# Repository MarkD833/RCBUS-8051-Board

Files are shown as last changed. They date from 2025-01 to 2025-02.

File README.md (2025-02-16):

# RCBUS-8051-Board

I've recently re-discovered some of the microprocessors and microcontrollers from my youth via the [RC2014 website](https://rc2014.co.uk/) and the numerous boards available on [Steve Cousins website](https://smallcomputercentral.com/).

The ecosystem is dominated by the Z80 processor and the various Z80 peripheral chips from that era along with the CP/M operating system which the hardware can run.

My introduction to computing started with an 8051 microcontroller and I've got an itch to have a go at putting together an 8051 design that will be compatible with the more open RCBus system. My background isn't hardware so apologies to the hardware designers for the horrors that I'm about to unleash!

# My 8051 RCBus offering
## The 8051 microcontroller
Whilst wanting to retain the retro experience, I wanted to skip the use of a UV eraser - as I don't have one! I initially settled on an ATMEL AT89C51RB2 device as it could be programmed by invoking an interal bootloader and using the free ATMEL FLIP software to program it in-circuit. For the most part it worked - with one HUGE gotcha!

It took me a while to figure it out but after re-reading the datasheet I discovered that there was a fuse bit that prohibited the device from executing code in external memory. The problem was that FLIP can't reprogram this bit to enable external program execution and a parallel programmer was required. My XGecu T48 programmer doesn't support the AT89C51RB2 and I wasn't about to purchase a new PROM programmer just to program this chip.

After searching for a suitable alternative device, I settled on the ATMEL AT89S8253 which is MCS51 compatible.

## External memory
I needed the ability to write to program memory to load code and I wanted to experiment to see if I could come up with a desgin that would be able to switch between the 8051's [Harvard architecture](https://en.wikipedia.org/wiki/Harvard_architecture) (where program memory and data memory are normally separate) and a [von Neumann architecture](https://en.wikipedia.org/wiki/Von_Neumann_architecture).

In order to have the maximum amount of code space and data space, I would need a 128K SRAM device.

## The RCBus
The RCBus supports both memory space and IO space. As I was going to have the maximum amout of addressable memory on-board, off-board memory space was not going to be supported. IO space is 256 bytes and is mapped into the data memory map.

# The design (so far...)
The design at v1.1 is shown in the image below. The board is hopefully the size of the RCBus "medium" module with a 40 pin edge connector as detailed in the [RCBus specification](https://smallcomputercentral.com/rcbus/) v1.0.

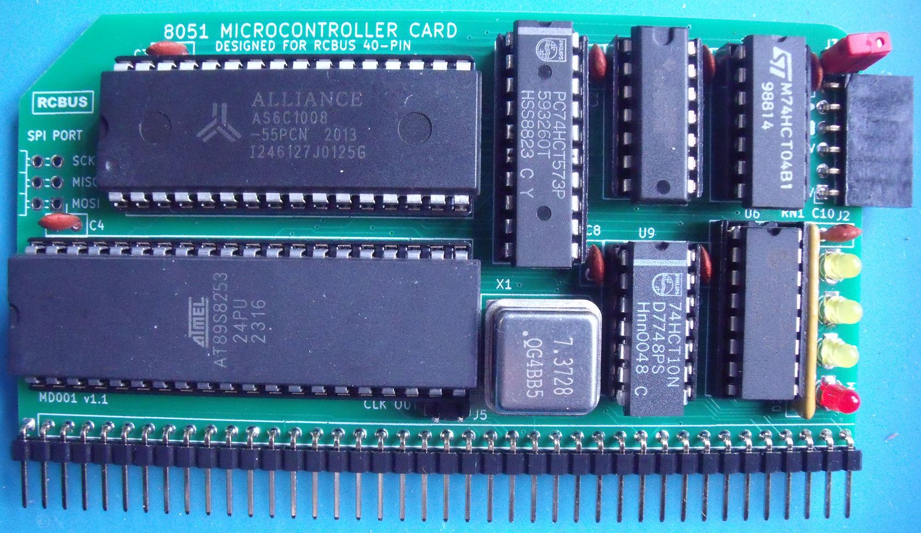
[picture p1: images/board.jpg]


# Memory Map

After a hard reset, the lower 12K of program memory ($0000..$2FFF) resides inside the AT89S8253 as FLASH memory and the bulk of the 64K block of RAM is shared between program space and data space.

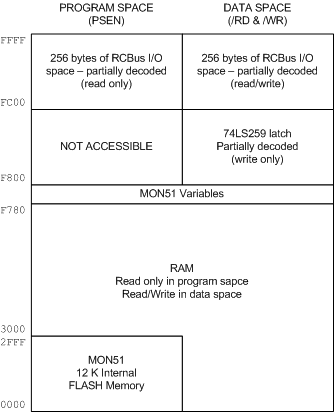
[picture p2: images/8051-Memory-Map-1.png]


# What works
I've ported Dave Dunfields MON51 monitor program over to the 89S8253. Most of the work involved getting the code to assemble using ASEM-51 v1.3 under Windows 10. The modified MON51 (MON51.a51) and original (MON51.ASM) are in the MON51 folder.

Currently:
* MON51 appears to function correctly
* Program space and data space are shared on power up
* Code can be downloaded via MON51 into the shared RAM and executed
* The on-board latch (74LS259) can be written to ($F800..$FBFF)
* RCBus IO space can be accessed ($FC00..$FFFF)
* Program space and data space can be separated (write $01 to $F801)
* Internal reboot works - can execute code in external memory starting at address $0000
 
## RCBus boards
The following boards appear to function correctly with the 8051 micro:
* SC129 Digital I/O Board
* SC704 I2C Bus Master Board (inc SC406 temperature module)
* SC705 Serial ACIA Board
 
# Still to do
* Further checks on the RCBus IO space using a few of Steve Cousins boards

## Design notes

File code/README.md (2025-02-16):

# Test code
This folder holds various pieces of code that test the 8051 board.

The assembler code should assemble under Windows 10 using [ASEM-51 v1.3](https://plit.de/asem-51/download.htm).

The code can be assembled using the simple command:
```
asemw <source-file-name>
```
# 8051 board tests
These bits of code test some functionality on the 8051 board.

## switch1.a51
This is a simple piece of code that tests the ability to separate program space from data space. It outputs a count to the LEDs on an [SC129](https://smallcomputercentral.com/rcbus/sc100-series/sc129-digital-i-o-rc2014/) digital I/O board. When the count reaches 15, the program space and data space are separated and the count should continue.

## switch2.a51
Simialr to switch1.a51 above except that it increments a variable in data space just to prove that the two memories are really separated.  

# RCBus and RC-2014 board test programs
## SC129 Digital I/O Board
The [SC129](https://smallcomputercentral.com/rcbus/sc100-series/sc129-digital-i-o-rc2014/) is a simple digital I/O module available from the [Small Computer Central](https://smallcomputercentral.com/) website.

| File | Description |
| :---- | :---- |
| count.a51 | Counts in binary on the LEDs of an SC129 board. |
| echo.a51 | Reads an SC129 input port and writes to its output port. |

## SC704 I2C Bus Master board
The [SC704](https://smallcomputercentral.com/rcbus/sc700-series/sc704-rcbus-i2c-bus-master/) implements a simple bit banged I2C bus master. As part of the testing, an [SC406](https://smallcomputercentral.com/i2c-bus-modules/sc406-i2c-temperature-sensor-module/) I2C temperature sensor module was used.

| File | Description |
| :---- | :---- |
| i2c_scan.a51 | Simple I2C bus scanner to detect I2C devices and report their addresses. |
| sc406.a51 | Reads the temperature of an SC406 temperature sensor. |

## SC705 Serial ACIA board
The [SC705](https://smallcomputercentral.com/rcbus/sc700-series/sc705-rcbus-serial-acia/) is a single channel UART (MC68B50) with a fixed baud rate (dependant on the external clock applied).

| File | Description |
| :---- | :---- |
| hello.a51 | Outputs "Hello World!" to the port. |
| echo.a51 | Echoes back any characters received. |

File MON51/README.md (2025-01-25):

# MON51 Monitor Program
The 8051 monitor program I'm using to get started is Dave Dunfields MON51. Dave has kindly made available 40+ years of source code via [his website](https://dunfield.themindfactory.com/).

I'm not sure what assembler was used to assemble the original assembly code (MON51.ASM). I therefore modified the code so that it would assemble under Windows 10 using [ASEM-51 v1.3](https://plit.de/asem-51/download.htm).

My modified version of MON51 - called MON51.a51 - for my RCBus 8051 board can be assembled using ASEM51 v1.3. I've also included the original copyright information from Dave Dunfield.

The monitor can be assembled using the simple command:
```
asemw mon51
```

The monitor adds LJMP instructions for the exception vectors to handlers starting at address $3000 and the baud rate is set to 38400 baud.

I've added a new Z command. This will set EA low, separate program memory from data memory (so each has its own memory space of almost 64K : $0000 to $F800) and internally reset the 8051 to execute code from external program memory starting at address $0000.
 
The original source code to MON51 can be found in the MONITOR.ZIP file on Dave's website along with MON51.TXT which is a brief user guide.

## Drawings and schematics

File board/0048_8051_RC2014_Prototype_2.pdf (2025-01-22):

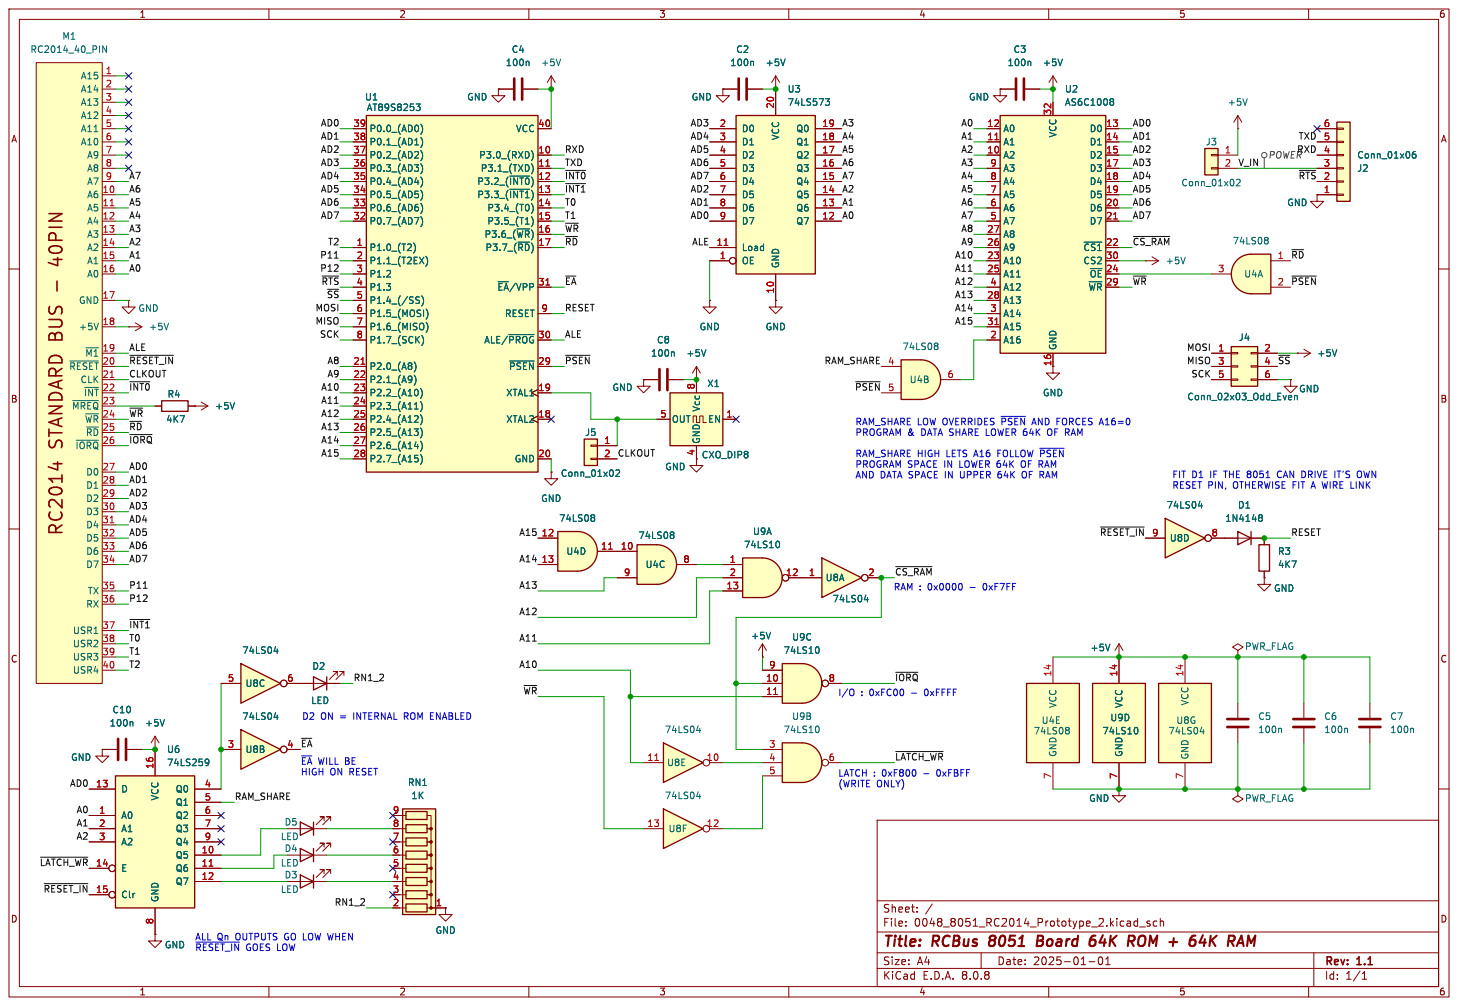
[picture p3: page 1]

A15 1 A6 10 A5 11 A4 12 A3 13 A2 14 A1 15 A0 16 GND 17 +5V 18 ~{M1}19 A14 2 ~{RESET} 20 CLK 21 ~{INT} 22 ~{MREQ} 23 ~{WR} 24 ~{RD} 25 ~{IORQ} 26 D0 27 D1 28 D2 29 A13 3 D3 30 D4 31 D5 32 D6 33 D7 34 TX 35 RX 36 USR1 37 USR2 38 USR3 39
A12 4 USR4 40

RAM_SHARE HIGH LETS A16 FOLLOW ~{PSEN} PROGRAM SPACE IN LOWER 64K OF RAM

AND DATA SPACE IN UPPER 64K OF RAM

RESET PIN, OTHERWISE FIT A WIRE LINK D2 ON = INTERNAL ROM ENABLED

(WRITE ONLY) ALL Qn OUTPUTS GO LOW WHEN

File: 0048_8051_RC2014_Prototype_2.kicad_sch Sheet: /
Id: 1/1 Title: RCBus 8051 Board 64K ROM + 64K RAM

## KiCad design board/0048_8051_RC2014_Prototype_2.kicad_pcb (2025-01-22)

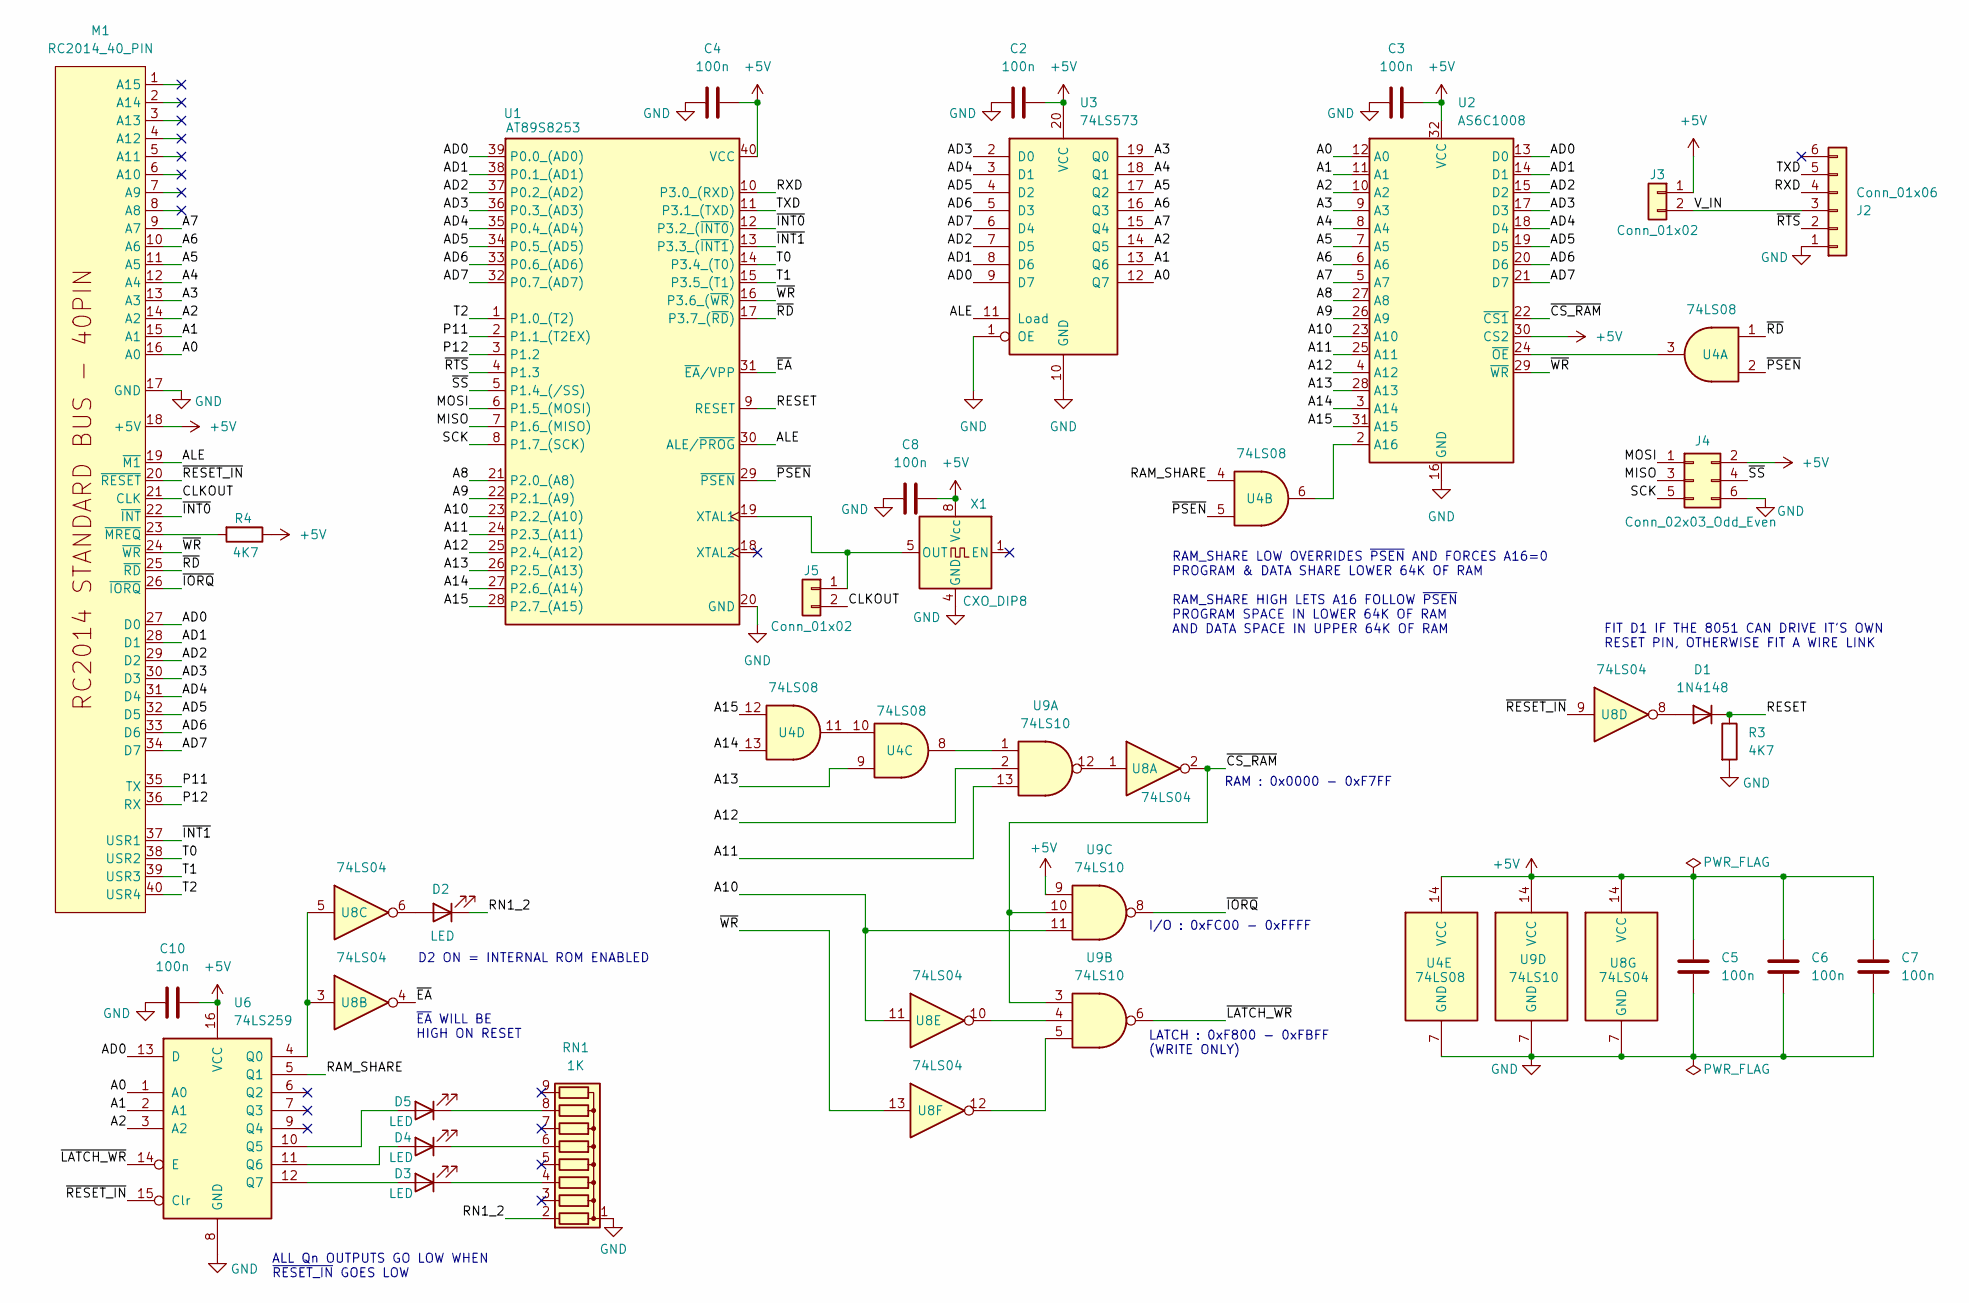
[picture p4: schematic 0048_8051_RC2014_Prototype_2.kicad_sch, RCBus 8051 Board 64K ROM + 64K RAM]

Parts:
C2, C3, C4, C5, C6, C7, C8, C10: 100n; C_Disc_D5.0mm_W2.5mm_P2.50mm
D1: 1N4148; D_DO-35_SOD27_P7.62mm_Horizontal
D2, D3, D4, D5: LED; LED_D3.0mm
J2: Conn_01x06; PinSocket_1x06_P2.54mm_Horizontal
J3, J5: Conn_01x02; PinHeader_1x02_P2.54mm_Vertical
J4: Conn_02x03_Odd_Even; PinHeader_2x03_P2.54mm_Horizontal
M1: RC2014_40_PIN; RCBUS_40P_MEDIUM
R3, R4: 4K7; R_Axial_DIN0207_L6.3mm_D2.5mm_P7.62mm_Horizontal
RN1: 1K; R_Array_SIP9
U1: AT89S8253; DIP-40_W15.24mm_Socket
U2: AS6C1008; DIP-32_W15.24mm_Socket
U3: 74LS573; DIP-20_W7.62mm_Socket
U4: 74LS08; DIP-14_W7.62mm_Socket
U6: 74LS259; DIP-16_W7.62mm_Socket
U8: 74LS04; DIP-14_W7.62mm_Socket
U9: 74LS10; DIP-14_W7.62mm_Socket
X1: CXO_DIP8; Oscillator_DIP-8

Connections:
+5V: C2.2, C3.2, C4.2, C5.1, C6.1, C7.1, C8.2, C10.2, J3.1, J4.2, M1.18 (+5V), R4.1, U1.40 (VCC), U2.30 (CS2), U2.32 (VCC), U3.20 (VCC), U4.14 (VCC), U6.16 (VCC), U8.14 (VCC), U9.9, U9.14 (VCC), X1.8 (Vcc)
/A0: M1.16 (A0), U2.12 (A0), U3.12 (Q7), U6.1 (A0)
/A1: M1.15 (A1), U2.11 (A1), U3.13 (Q6), U6.2 (A1)
/A2: M1.14 (A2), U2.10 (A2), U3.14 (Q5), U6.3 (A2)
/A3: M1.13 (A3), U2.9 (A3), U3.19 (Q0)
/A4: M1.12 (A4), U2.8 (A4), U3.18 (Q1)
/A5: M1.11 (A5), U2.7 (A5), U3.17 (Q2)
/A6: M1.10 (A6), U2.6 (A6), U3.16 (Q3)
/A7: M1.9 (A7), U2.5 (A7), U3.15 (Q4)
/A8: U1.21 (P2.0_(A8)), U2.27 (A8)
/A9: U1.22 (P2.1_(A9)), U2.26 (A9)
/A10: U1.23 (P2.2_(A10)), U2.23 (A10), U8.11, U9.11
/A11: U1.24 (P2.3_(A11)), U2.25 (A11), U9.13
/A12: U1.25 (P2.4_(A12)), U2.4 (A12), U9.2
/A13: U1.26 (P2.5_(A13)), U2.28 (A13), U4.9
/A14: U1.27 (P2.6_(A14)), U2.3 (A14), U4.13
/A15: U1.28 (P2.7_(A15)), U2.31 (A15), U4.12
/AD0: M1.27 (D0), U1.39 (P0.0_(AD0)), U2.13 (D0), U3.9 (D7), U6.13 (D)
/AD1: M1.28 (D1), U1.38 (P0.1_(AD1)), U2.14 (D1), U3.8 (D6)
/AD2: M1.29 (D2), U1.37 (P0.2_(AD2)), U2.15 (D2), U3.7 (D5)
/AD3: M1.30 (D3), U1.36 (P0.3_(AD3)), U2.17 (D3), U3.2 (D0)
/AD4: M1.31 (D4), U1.35 (P0.4_(AD4)), U2.18 (D4), U3.3 (D1)
/AD5: M1.32 (D5), U1.34 (P0.5_(AD5)), U2.19 (D5), U3.4 (D2)
/AD6: M1.33 (D6), U1.33 (P0.6_(AD6)), U2.20 (D6), U3.5 (D3)
/AD7: M1.34 (D7), U1.32 (P0.7_(AD7)), U2.21 (D7), U3.6 (D4)
/ALE: M1.19 (~M1), U1.30 (ALE/~PROG), U3.11 (Load)
/CLKOUT: J5.2, M1.21 (CLK)
/MISO: J4.3, U1.7 (P1.6_(MISO))
/MOSI: J4.1, U1.6 (P1.5_(MOSI))
/P11: M1.35 (TX), U1.2 (P1.1_(T2EX))
/P12: M1.36 (RX), U1.3 (P1.2)
/RAM_SHARE: U4.4, U6.5 (Q1)
/RESET: D1.1 (K), R3.1, U1.9 (RESET)
/RN1_2: D2.1 (K), RN1.2 (R1)
/RXD: J2.4, U1.10 (P3.0_(RXD))
/SCK: J4.5, U1.8 (P1.7_(SCK))
/T0: M1.38 (USR2), U1.14 (P3.4_(T0))
/T1: M1.39 (USR3), U1.15 (P3.5_(T1))
/T2: M1.40 (USR4), U1.1 (P1.0_(T2))
/TXD: J2.5, U1.11 (P3.1_(TXD))
/V_IN: J2.3, J3.2
/~CS_RAM: U2.22 (~CS1), U8.2, U9.3, U9.10
/~EA: U1.31 (~EA/VPP), U8.4
/~INT0: M1.22 (~INT), U1.12 (P3.2_(~INT0))
/~INT1: M1.37 (USR1), U1.13 (P3.3_(~INT1))
/~IORQ: M1.26 (~IORQ), U9.8
/~LATCH_WR: U6.14 (E), U9.6
/~PSEN: U1.29 (~PSEN), U4.2, U4.5
/~RD: M1.25 (~RD), U1.17 (P3.7_(~RD)), U4.1
/~RESET_IN: M1.20 (~RESET), U6.15 (Clr), U8.9
/~RTS: J2.2, U1.4 (P1.3)
/~SS: J4.4, U1.5 (P1.4_(/SS))
/~WR: M1.24 (~WR), U1.16 (P3.6_(~WR)), U2.29 (~WR), U8.13
GND: C2.1, C3.1, C4.1, C5.2, C6.2, C7.2, C8.1, C10.1, J2.1, J4.6, M1.17 (GND), R3.2, RN1.1 (common), U1.20 (GND), U2.16 (GND), U3.1 (OE), U3.10 (GND), U4.7 (GND), U6.8 (GND), U8.7 (GND), U9.7 (GND), X1.4 (GND)
unnamed: D1.2 (A), U8.8
unnamed: D2.2 (A), U8.6
unnamed: D3.2 (A), U6.12 (Q7)
unnamed: D3.1 (K), RN1.4 (R3)
unnamed: D4.2 (A), U6.11 (Q6)
unnamed: D4.1 (K), RN1.6 (R5)
unnamed: D5.2 (A), U6.10 (Q5)
unnamed: D5.1 (K), RN1.8 (R7)
unnamed: J5.1, U1.19 (XTAL1), X1.5 (OUT)
unnamed: M1.23 (~MREQ), R4.2
unnamed: U2.2 (A16), U4.6
unnamed: U2.24 (~OE), U4.3
unnamed: U4.8, U9.1
unnamed: U4.10, U4.11
unnamed: U6.4 (Q0), U8.3, U8.5
unnamed: U8.1, U9.12
unnamed: U8.10, U9.4
unnamed: U8.12, U9.5

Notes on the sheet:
ALL Qn OUTPUTS GO LOW WHEN ~{RESET_IN} GOES LOW
D2 ON = INTERNAL ROM ENABLED
RAM_SHARE LOW OVERRIDES ~{PSEN} AND FORCES A16=0 PROGRAM & DATA SHARE LOWER 64K OF RAM RAM_SHARE HIGH LETS A16 FOLLOW ~{PSEN} PROGRAM SPACE IN LOWER 64K OF RAM AND DATA SPACE IN UPPER 64K OF RAM
FIT D1 IF THE 8051 CAN DRIVE IT'S OWN RESET PIN, OTHERWISE FIT A WIRE LINK
~{EA} WILL BE HIGH ON RESET
I/O : 0xFC00 - 0xFFFF
LATCH : 0xF800 - 0xFBFF (WRITE ONLY)
RAM : 0x0000 - 0xF7FF

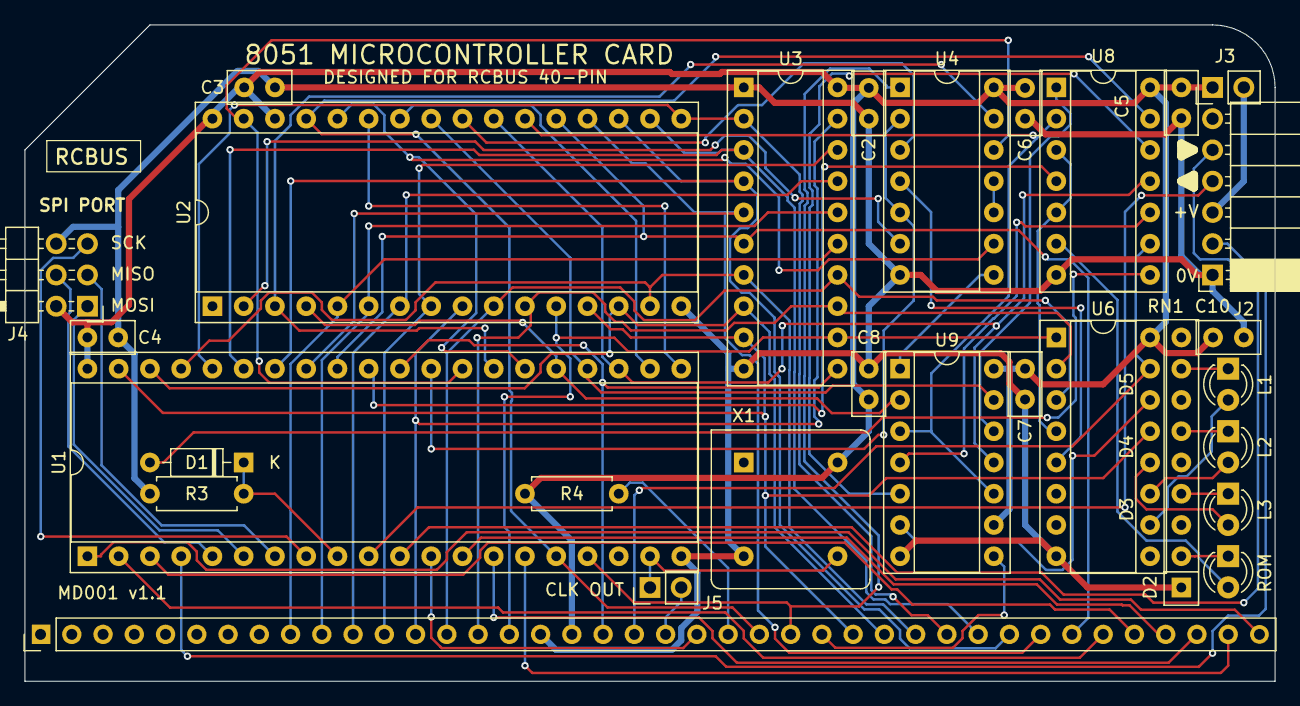
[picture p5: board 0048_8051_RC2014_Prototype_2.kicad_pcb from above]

Board: 2 copper layers, 101.6 x 53.3 mm, 29 parts (0 on the bottom side), 72 nets.
